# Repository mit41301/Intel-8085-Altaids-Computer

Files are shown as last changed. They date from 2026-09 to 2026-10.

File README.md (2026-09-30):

# Intel 80C85 Altaids Computer

[Build a Pocket-Sized Altair Computer](https://www.nutsvolts.com/magazine/article/build-a-pocket-sized-altair-computer) By David Hunter



Altaids_20260930T

https://www.tindie.com/products/retrocomputer/8085-chip-computer-pocket-sized-z80-altoids/

https://www.tindie.com/products/nkk_electronic/8085-sbc-altair-style-mini-board-altoids/

# Mint tin dimensions:
Top lid outer (not lip): 2.36" (59.9mm) x 3.75"(95mm)  
Tin bottom: 2.3" (58.75mm) x 3.7"(93.9mm)  
Inner: 2.24" (56.9mm) x 3.6"(91.5mm)  
Height bottom section: 0.83" (21.28mm)  
Height top section: "0.36 (9.26mm)  
Corner radius .55" (14mm)  

    "X": 91.44 mm  
    "Y": 56.896 mm  



# A85 8085 cross-assembler

A85 8085 cross-assembler can be found from Herb Johnson's [SITE](https://www.retrotechnology.com/restore/a85.html) and it works on Windows 11!

command line: A85 altaidsRom.asm -l altaids.lst -o altaids.hex

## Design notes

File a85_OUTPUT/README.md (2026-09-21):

C:\DOS\a85>a85 AltaidsROM.asm -o AltaidsROM.hex -l AltaidsROM.prn -s AltaidsROM.sym  
8085 Cross-Assembler (Portable) Ver 0.1+4  
Copyright (c) 1985,1987 William C. Colley, III  
fixes Copyright (c) 2026 Herbert R. Johnson HRJ Aug 2026  

No Errors  

[8085 Cross-Assembler](https://www.retrotechnology.com/restore/a85.html)

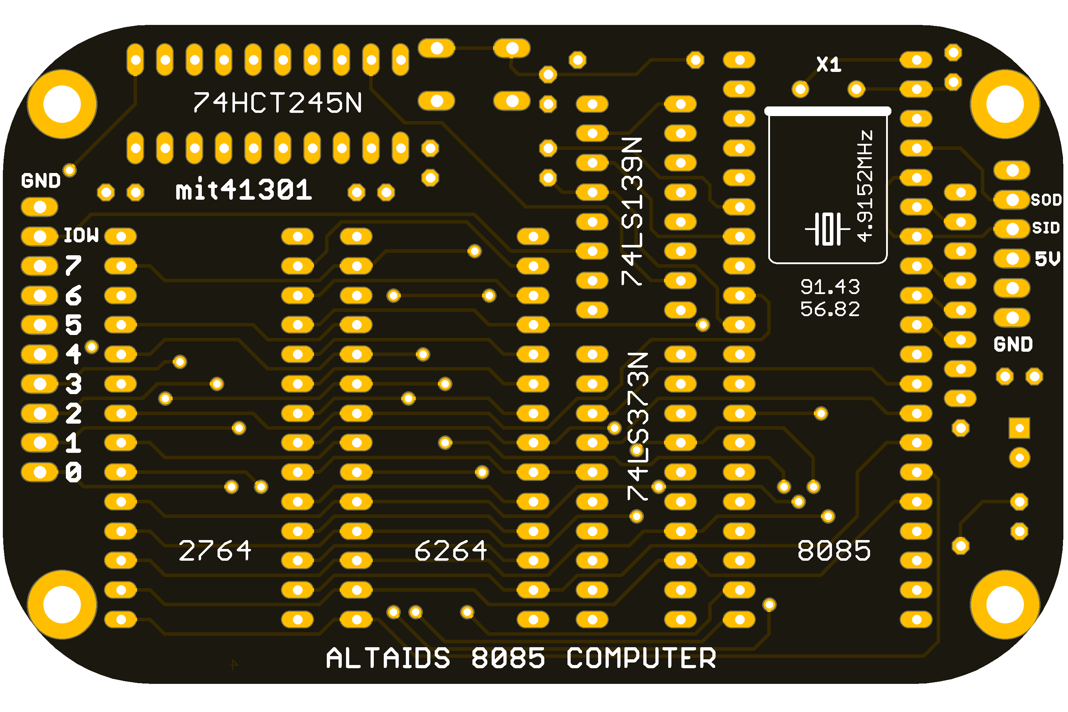
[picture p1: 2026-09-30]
Altoids_Eagle/Altaids_20260930B.png

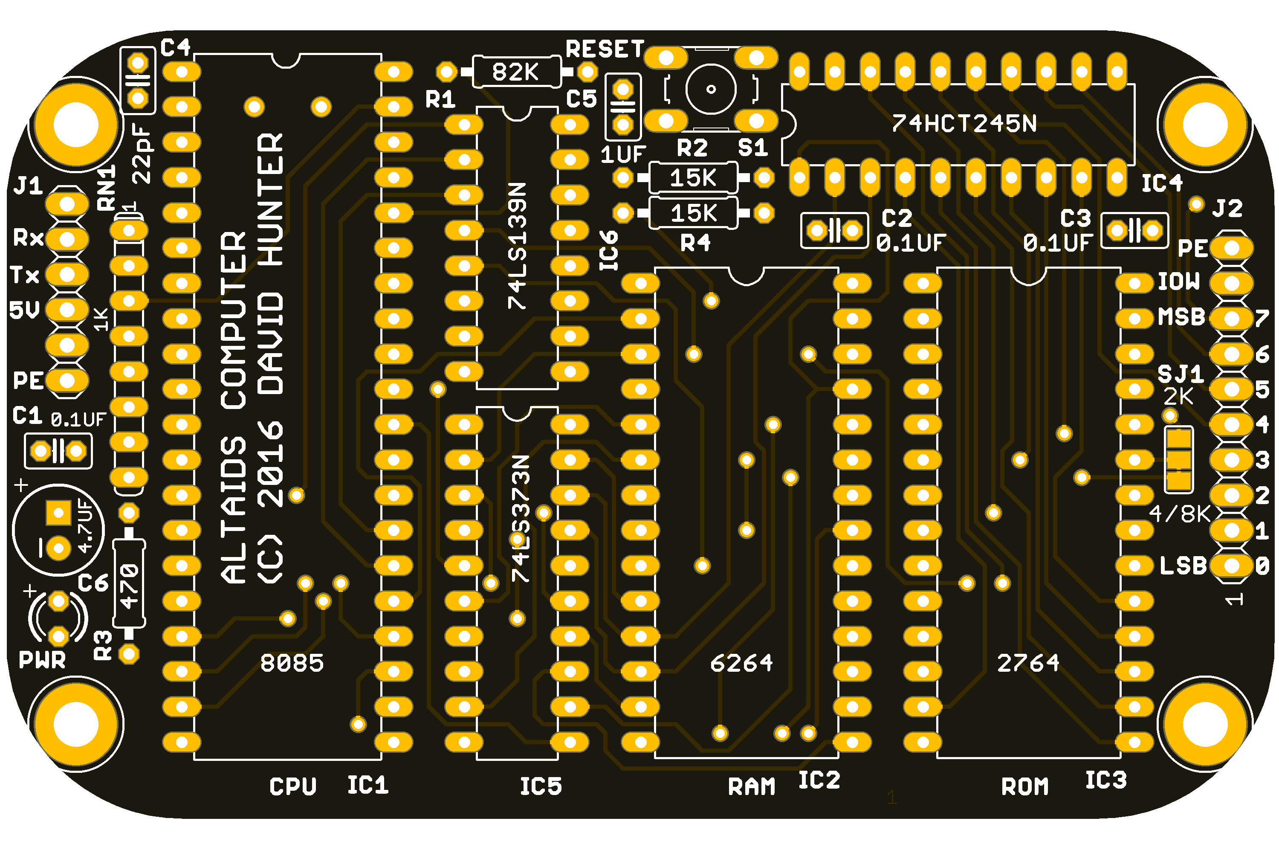
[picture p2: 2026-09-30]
Altoids_Eagle/Altaids_20260930T.png

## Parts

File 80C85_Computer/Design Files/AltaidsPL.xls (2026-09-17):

Altaids Computer
Parts List
Qty. | REF DES | Distributor P/N | Distributor | Description | Notes
3 | C1,C2,C3 | 75-1C10Z5U104M050B | Mouser | CAPACITOR, CER, 0.1UF
 |  | 332672 | Jameco | CAPACITOR, CER, 0.1UF
1 | C4 | 75-1C10C0G220J050B | Mouser | CAPACITOR, CER, 22PF
 |  | 332541 | Jameco | CAPACITOR, CER, 22PF
1 | C5 | 810-FK18X5R1E105K | Mouser | CAPACITOR, CER, 1UF
 |  | 544956 | Jameco | CAPACITOR, CER, 1UF | Re-bend leads to 0.1”
 |  | 545588 | Jameco | CAPACITOR, TANT, 1UF | Alternate
1 | C6 | 647-UVR2C4R7MED1TD | Mouser | CAPACITOR, ELECT, 4.7uF, 160V
 |  | 667-ECA-2CM4R7 | Mouser | CAPACITOR, ELECT, 4.7uF, 160V
 |  | 546071 | Jameco | CAPACITOR, TANT, 4.7uF, 25V | Alternate
1 | IC1 | 52062 | Jameco | MICROPROCESSOR, 8085
1 | IC2 | 42892 | Jameco | SRAM, 8K x 8
 |  | 913-AS6C6264A-70PCN | Mouser | SRAM, 8K x 8
1 | IC3 | 74827 | Jameco | EEPROM, 8K x 8
1 | IC4 | 45031 | Jameco | 74HCT245N
1 | IC5 | 47600 | Jameco | 74LS373N
 |  | 595-SN74LS373N | Mouser | 74LS373N
1 | IC6 | 46623 | Jameco | 74LS139N
 |  | 595-SN74LS139AN | Mouser | 74LS139N
1 | J1 | 153700 | Jameco | MALE HEADER, 1X6
 |  | 538-22-28-4063 | Mouser | MALE HEADER, 1X6
1 | J2 | 2172560 | Jameco | FEMALE HEADER, 1X10
 |  | 649-75915-310LF | Mouser | FEMALE HEADER, 1X10
1 | LED1 | 2155241 | Jameco | LED3MM
 |  | 755-SLI-343Y8C3F | Mouser | LED3MM
1 | R1 | 660-MF1/4LCT52R823G | Mouser | RESISTOR, 82K, 1/4W
 |  | 691323 | Jameco | RESISTOR, 82K, 1/4W
2 | R2,R4 | 603-MFR-25FRF5215K | Mouser | RESISTOR, 15K, 1/4W
 |  | 691147 | Jameco | RESISTOR, 15K, 1/4W
1 | R3 | 660-MF1/4LCT52R331J | Mouser | RESISTOR, 330, 1/4W
 |  | 690742 | Jameco | RESISTOR, 330, 1/4W
1 | RN1 | 652-4608X-1LF-1K | Mouser | RESISTOR NETWORK, SIP, 7POS, 1K
 |  | 97826 | Jameco | RESISTOR NETWORK, SIP, 7POS, 10K | Alternate
1 | SW1 | 162886 | Jameco | PUSHBUTTON, SPST, 4P
1 | X1 | 774-MP042 | Mouser | CRYSTAL, 4.9152MHz, HC49U
1 | IC1-S | 41136 | Jameco | Socket, 40P 0.6” DIP
 |  | 571-5-1571552-2 | Mouser | Socket, 40P 0.6” DIP
2 | IC2-S,IC3-S | 40328 | Jameco | Socket, 28P 0.6” DIP
 |  | 571-2-1571552-9 | Mouser | Socket, 28P 0.6” DIP
2 | IC4-S,IC5-S | 38623 | Jameco | Socket, 20P 0.3” DIP
 |  | 575-913204 | Mouser | Socket, 20P 0.3” DIP
1 | IC6-S | 37402 | Jameco | Socket, 16P 0.3” DIP
 |  | 571-2-1571552-4 | Mouser | Socket, 16P 0.3” DIP
4 | H1,H2,H3,H4 | 761-2100-440-AL-7 | Mouser | Hex Female Standoff, 0.25”, 4-40
 |  | 133613 | Jameco | Hex Female Standoff, 0.25”, 4-40
4 | H1,H2,H3,H4 | 2094389 | Jameco | Screw, Pan Head, Phillips, 0.25”, 4-40
 |  | 534-9900 | Mouser | Screw, Pan Head, Phillips, 0.25”, 4-40

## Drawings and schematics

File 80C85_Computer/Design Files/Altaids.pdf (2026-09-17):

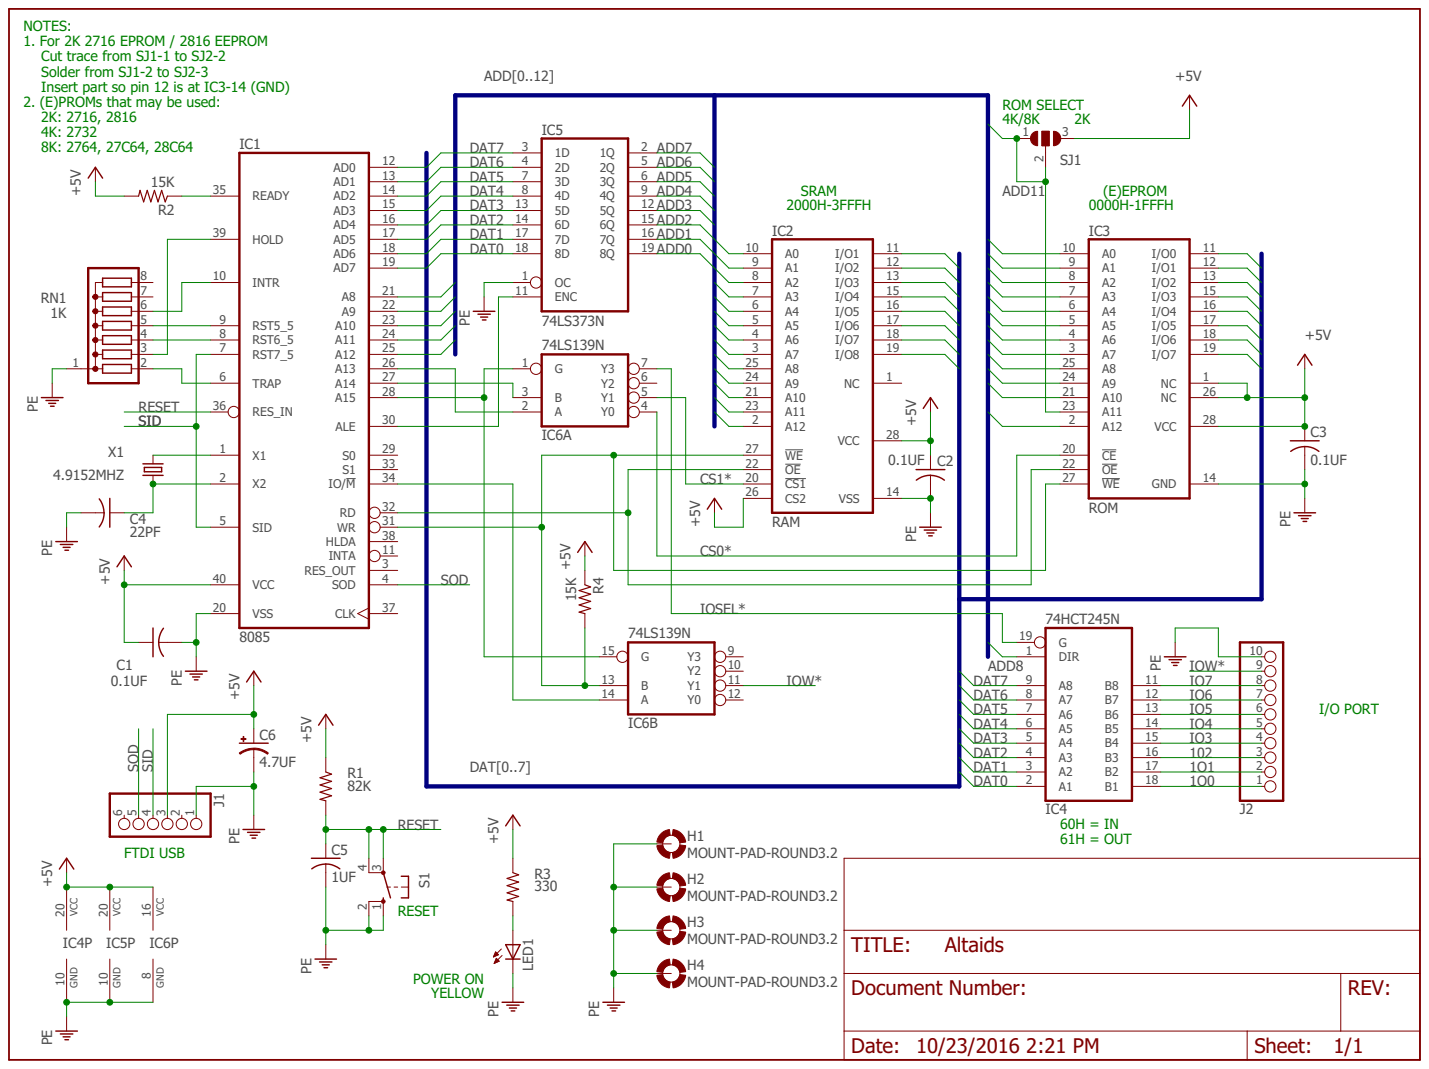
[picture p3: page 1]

NOTES: 1. For 2K 2716 EPROM / 2816 EEPROM

Cut trace from SJ1-1 to SJ2-2
Solder from SJ1-2 to SJ2-3
Insert part so pin 12 is at IC3-14 (GND)
2. (E)PROMs that may be used: 2K: 2716, 2816

Document Number: | REV:

Date: 10/23/2016 2:21 PM | Sheet: 1/1

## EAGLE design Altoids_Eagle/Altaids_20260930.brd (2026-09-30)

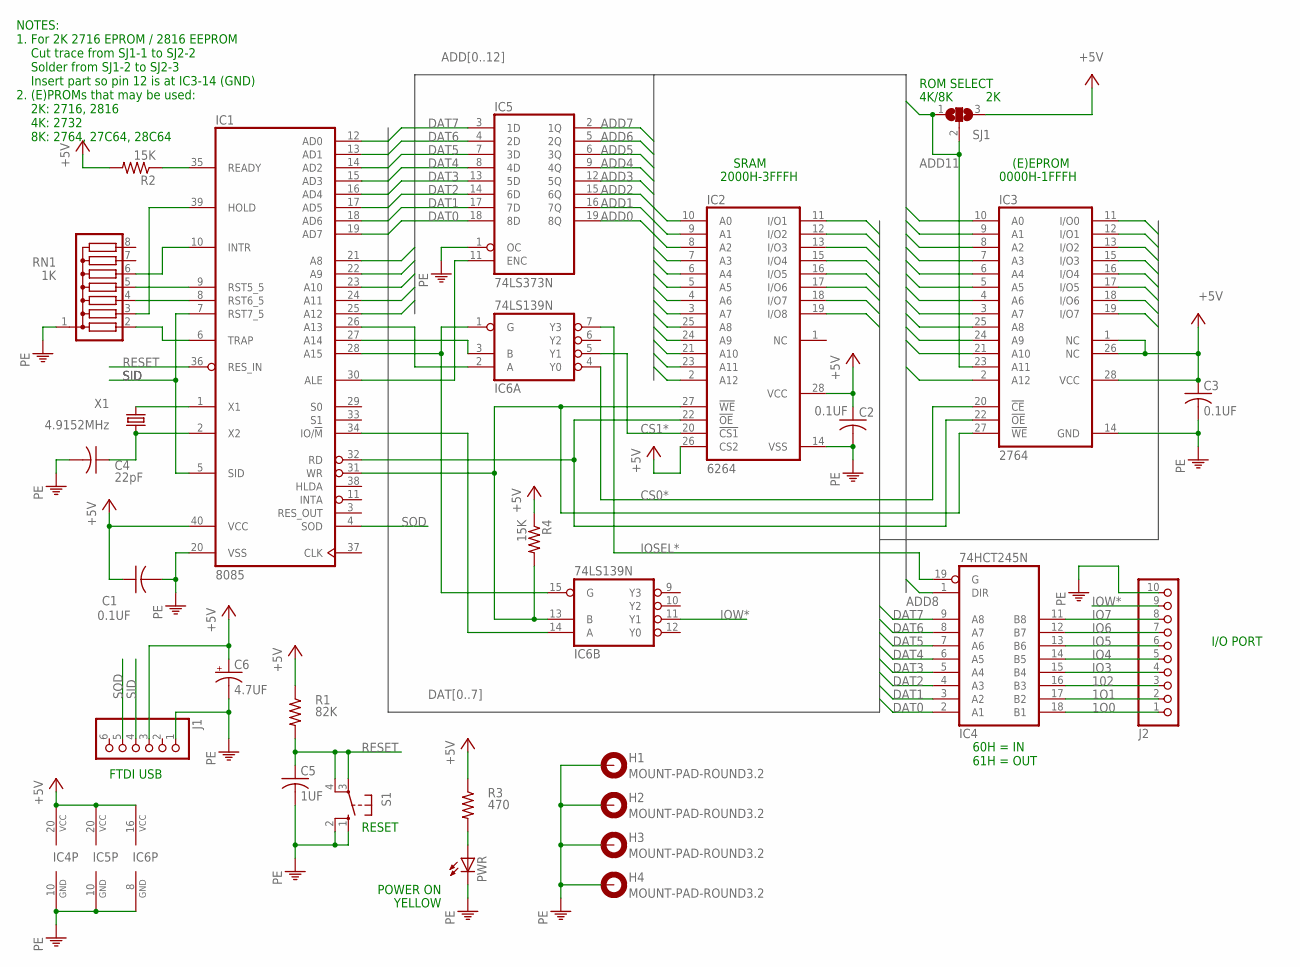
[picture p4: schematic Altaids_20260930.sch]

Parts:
C1, C2, C3: 0.1UF; C025-025X050
C4: 22pF; C025-025X050
C5: 1UF; C025-025X050
C6: 4.7UF; CPOL-RADIAL-100UF-25V
H1, H2, H3, H4: MOUNT-PAD-ROUND3.2; 3,2-PAD
IC1: 8085; DIL40
IC2: 6264; DIL28-6
IC3: 2764; DIL28-6
IC4: 74HCT245N; DIL20
IC5: 74LS373N; DIL20
IC6: 74LS139N; DIL16
J1: PINHD-1X6; 1X06
J2: PINHD-1X10; 1X10
PWR: LED3MM
R1: 82K; 0207/10
R2, R4: 15K; 0207/10
R3: 470; 0207/10
RN1: 1K; SIL8
S1: 10-XX; B3F-10XX
SJ1: SJ2W; SJ_2
X1: 4.9152MHz; HC49U-H

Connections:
1O0: IC4.18 (B1), J2.1
1O1: IC4.17 (B2), J2.2
102: IC4.16 (B3), J2.3
+5V: C1.1, C2.1, C3.1, C6.1 (+), IC1.40 (VCC), IC2.26 (CS2), IC2.28 (VCC), IC3.1 (NC), IC3.26 (NC), IC3.28 (VCC), IC4.20 (VCC), IC5.20 (VCC), IC6.16 (VCC), J1.3, R1.1, R2.2, R3.1, R4.1, SJ1.3
ADD0: IC2.10 (A0), IC3.10 (A0), IC5.19 (8Q)
ADD1: IC2.9 (A1), IC3.9 (A1), IC5.16 (7Q)
ADD2: IC2.8 (A2), IC3.8 (A2), IC5.15 (6Q)
ADD3: IC2.7 (A3), IC3.7 (A3), IC5.12 (5Q)
ADD4: IC2.6 (A4), IC3.6 (A4), IC5.9 (4Q)
ADD5: IC2.5 (A5), IC3.5 (A5), IC5.6 (3Q)
ADD6: IC2.4 (A6), IC3.4 (A6), IC5.5 (2Q)
ADD7: IC2.3 (A7), IC3.3 (A7), IC5.2 (1Q)
ADD8: IC1.21 (A8), IC2.25 (A8), IC3.25 (A8), IC4.1 (DIR)
ADD9: IC1.22 (A9), IC2.24 (A9), IC3.24 (A9)
ADD10: IC1.23 (A10), IC2.21 (A10), IC3.21 (A10)
ADD11: IC1.24 (A11), IC2.23 (A11), IC3.23 (A11), SJ1.1, SJ1.2
ADD12: IC1.25 (A12), IC2.2 (A12), IC3.2 (A12)
CS0*: IC3.20 (!CE), IC6.4 (Y0)
CS1*: IC2.20 (!CS1), IC6.5 (Y1)
DAT0: IC1.12 (AD0), IC2.11 (I/O1), IC3.11 (I/O0), IC4.2 (A1), IC5.18 (8D)
DAT1: IC1.13 (AD1), IC2.12 (I/O2), IC3.12 (I/O1), IC4.3 (A2), IC5.17 (7D)
DAT2: IC1.14 (AD2), IC2.13 (I/O3), IC3.13 (I/O2), IC4.4 (A3), IC5.14 (6D)
DAT3: IC1.15 (AD3), IC2.15 (I/O4), IC3.15 (I/O3), IC4.5 (A4), IC5.13 (5D)
DAT4: IC1.16 (AD4), IC2.16 (I/O5), IC3.16 (I/O4), IC4.6 (A5), IC5.8 (4D)
DAT5: IC1.17 (AD5), IC2.17 (I/O6), IC3.17 (I/O5), IC4.7 (A6), IC5.7 (3D)
DAT6: IC1.18 (AD6), IC2.18 (I/O7), IC3.18 (I/O6), IC4.8 (A7), IC5.4 (2D)
DAT7: IC1.19 (AD7), IC2.19 (I/O8), IC3.19 (I/O7), IC4.9 (A8), IC5.3 (1D)
IO3: IC4.15 (B4), J2.4
IO4: IC4.14 (B5), J2.5
IO5: IC4.13 (B6), J2.6
IO6: IC4.12 (B7), J2.7
IO7: IC4.11 (B8), J2.8
IOSEL*: IC4.19 (G), IC6.7 (Y3)
IOW*: IC6.11 (Y1), J2.9
unnamed: IC1.35 (READY), R2.1
unnamed: IC1.39 (HOLD), RN1.3
unnamed: IC1.10 (INTR), RN1.6
unnamed: IC1.9 (RST5_5), RN1.5
unnamed: IC1.8 (RST6_5), RN1.4
unnamed: IC1.6 (TRAP), RN1.2
unnamed: IC1.28 (A15), IC6.1 (G), IC6.15 (G)
unnamed: IC1.31 (WR), IC2.27 (!WE), IC3.27 (!WE), IC6.13 (B), R4.2
unnamed: PWR.A, R3.2
unnamed: C4.1, IC1.2 (X2), X1.1
unnamed: IC1.1 (X1), X1.2
unnamed: IC1.34 (IO/!M), IC6.14 (A)
unnamed: IC1.30 (ALE), IC5.11 (ENC)
unnamed: IC1.27 (A14), IC6.3 (B)
unnamed: IC1.26 (A13), IC6.2 (A)
unnamed: IC1.32 (RD), IC2.22 (!OE), IC3.22 (!OE)
PE: C1.2, C2.2, C3.2, C4.2, C5.2, C6.2 (-), H1.B3,2, H2.B3,2, H3.B3,2, H4.B3,2, IC1.20 (VSS), IC2.14 (VSS), IC3.14 (GND), IC4.10 (GND), IC5.1 (OC), IC5.10 (GND), IC6.8 (GND), J1.1, J2.10, PWR.K (C), RN1.1, S1.1 (S), S1.2 (S1)
RESET: C5.1, IC1.36 (RES_IN), R1.2, S1.3, S1.4 (P1)
SID: IC1.5 (SID), IC1.7 (RST7_5), J1.4
SOD: IC1.4 (SOD), J1.5

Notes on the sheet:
4K/8K
(E)EPROM
SRAM
FTDI USB
I/O PORT
ROM SELECT
POWER ON
YELLOW
RESET
60H = IN 61H = OUT
2000H-3FFFH
0000H-1FFFH
NOTES: 1. For 2K 2716 EPROM / 2816 EEPROM Cut trace from SJ1-1 to SJ2-2 Solder from SJ1-2 to SJ2-3 Insert part so pin 12 is at IC3-14 (GND) 2. (E)PROMs that may be used: 2K: 2716, 2816 4K: 2732 8K: 2764, 27C64, 28C64

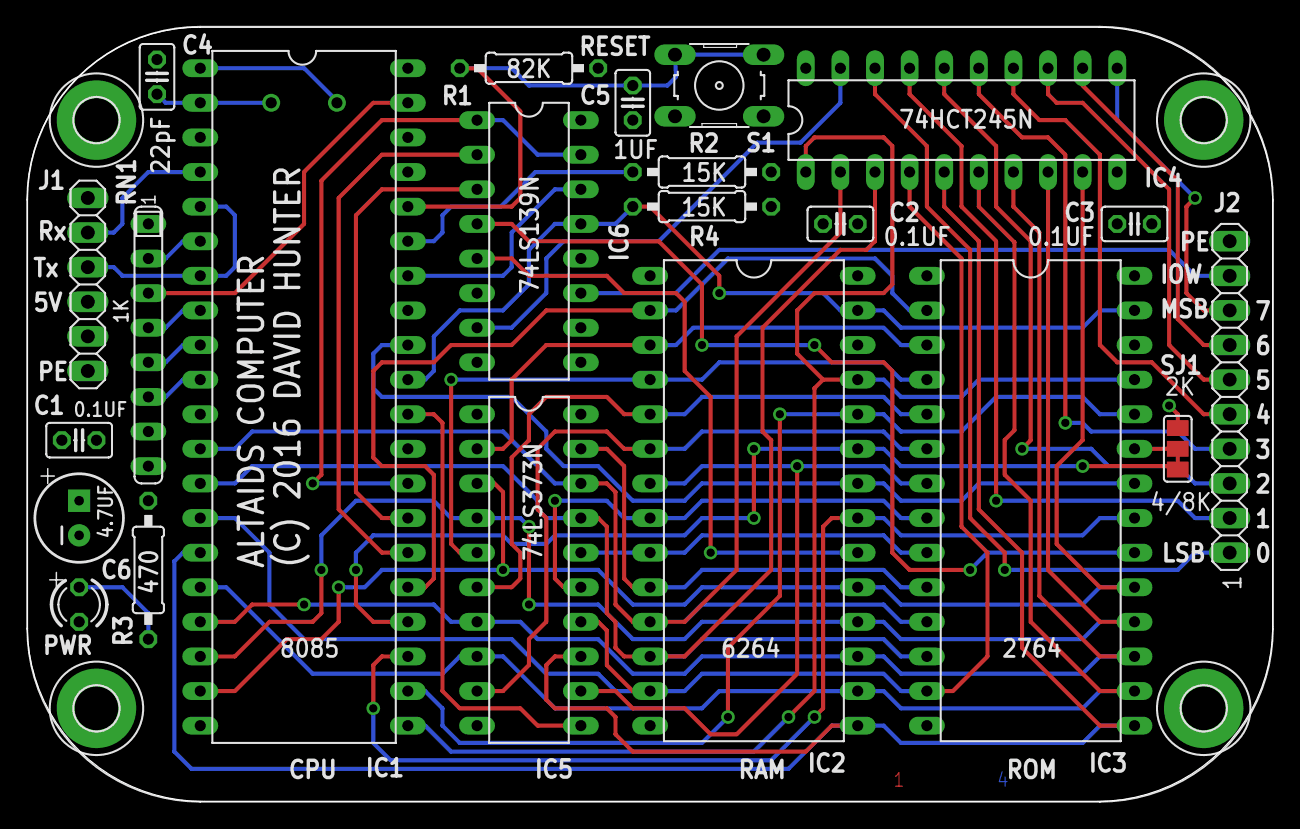
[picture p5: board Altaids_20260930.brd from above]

Board: 4 copper layers, 91.4 x 56.8 mm, 28 parts (1 on the bottom side), 54 nets.

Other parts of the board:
U$1: ALTOIDSTIN

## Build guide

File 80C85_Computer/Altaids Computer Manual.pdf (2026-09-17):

Altaids computer
Software Manual | 09/10/18

MONITOR
The operating system of the Altaids computer is a program known as a “monitor program.” This program allows for interacting with the computer over a serial port and debugging the programs. Commands consist of simple one or two letter command followed by hexadecimal values. Monitor programs were very popular with early computers. These programs allowed values to be written directly to memory, displaying memory, reading and writing Intel Hex files, etc. The monitor prompt is an asterisk '*'.

Monitor Start Up and Prompt
Altaids Monitor Ver 05
Copyright (C) 2018 David R. Hunter
This program comes with ABSOLUTELY NO WARRANTY
This is free software, and you are welcome to redistribute it under certain conditions; see the GNU GPL Version 3 for details Type "B" for BASIC, “H” for help
Type ^X to return to the Monitor
*

MONITOR COMMANDS

CMD: A
Enter Altair Turnkey Monitor (see below)

CMD: B
Start Tiny BASIC

CMD: Dssss eeee
Dump memory from address ssss to eeee. After ssss is entered, a space will automatically be generated.

CMD: Eaaaa
Write to memory starting at address aaaa. The address will be printed with the current byte. Type a new byte (in hexadecimal) to change. Press <SPACE> to skip the address leaving it unchanged. Type any other character to exit.

CMD: Gaaaa
Go (execute) a program from address aaaa

CMD: H
Help / Display monitor commands

CMD: I
Input a byte from port 60H and display

CMD: L
Load an Intel Hex file. Send the text file from the terminal emulator.
A '.' is printed for each record received correctly, a '?' if there is a checksum error, a '!' is printed when done

CMD: Obb
Output byte bb to port 61H

CMD: R
Display the values of the registers. Program Counter, Stack Pointer, Accumulator, Processor flags, BC,DE,HL. The flags are: Sign, Zero, Auxiliary carry, Parity, and Carry. An example is below

PC :SP :A SZ_A_P_C:B C :D E :H L
11CB 3F9E 22 00000100 01D2 1082 11C8

CMD: Taaaa
Single Step (trace) instructions starting at address aaaa. Type any key to step. Type ^C to exit. Each step shows the registers and a disassembled instruction. See the example below for details.

MONITOR ADDRESS VECTORS
The ROM subroutine addresses below may be useful for writing programs on the Altaids computer.

MONITOR JUMP ADDRESSES
1000 COLD | Monitor cold start
1003 WARM | Tiny BASIC warm start (return to BASIC without losing program in memory with G1003)

MONITOR VECTORS TO USEFUL ROUTINES (ENTER WITH CALL OPCODE)
1006 COUT | Output char in A to serial port
1009 CIN | Input char from serial port to A
100C PRTWD | Output H,L as 4 Hex digits to serial port
100F PRTBY | Output the byte in A as 2 Hex digits to serial port
1012 GETWD | Get Hex word from serial port, return in H,L
1015 GETBY | Get Hex byte from serial port, return in A
1018 PIN | Get byte from input port, return in A
101B POUT | Send byte in A to output port
101E DSPREG | Display registers (registers are restored upon return)
1021 PUTSTR | Send null terminated string pointed to by DE to serial port

ALTAIR MONITOR
The Altair monitor was adapted from the Altair Turnkey Monitor (TURMON) for the Altaids Computer. It is more limited than the Altaids monitor and operates with Octal values only. It is provided to “relive” the experience of operating an original Altair computer.

Altair Monitor Prompt character: '.'

Commands:
Mxxxxxx - change memory location xxxxxx (octal)
- enter 3 octal digits for new data
- press <SPACE> to skip to next location
- any other character to exit

Dxxxxxx xxxxxx - dump data from start to end address
- originally in Altair 8800b binary Absolute Tape Format
- now changed to a more standard memory dump

Jxxxxxx - jump to location and begin executing

TINY BASIC

Palo Altaids Tiny BASIC is an integer only BASIC. It is a modified version of Palo Alto Tiny BASIC by LiChen Wang. This was one of the most popular Tiny BASIC implementations for the Intel 8080.

All numbers are 16 bit values between -32767 and 32767. There are 26 variables A-Z. There is a single large one dimensional array '@(n)'. The @ array uses all remaining memory, so it's size depends on the length of the program. The number of elements is from 0 to SIZE/2. Also, one dimensional array variables may be defined using the DIM statement. Defined arrays reduce the size of memory available for the @ array.

Note, all values are decimal, so address values are expressed as decimal values. (e.g. 8192 = 0x2000)

Line numbers are from 1 to 32767. To add a line, type the line number and statement(s). To delete a line, enter the line number by itself.

There is a “one line screen editor” available which requires an ANSI compatible terminal or emulator (e.g. VT100). To edit a line, type “EDIT <line num>”. The prompt will change to ']' and the line to edit will be displayed. Use the left and right arrows to move about the line. The <DEL> key will delete the character under the cursor. The <BACKSPACE> key will delete the character to the left (unless at the line number). Any characters typed will automatically be inserted. The <ENTER> key will erase to the end of the line and exit the editor saving the line. To exit the editor and save the line press <F1>. Note, the line number cannot be changed with the editor.

Tiny BASIC can use an external computer running a terminal emulator (like TeraTerm) to load and store programs. The files are transferred using the XMODEM protocol (checksum mode only). This allows another computer to provide storage for programs. Files transferred via XMODEM typically use a “.TBI” extension. The files transferred are binary files.

When Tiny BASIC is ready, the prompt is '>'. When a command is successful there terminal will show “OK” followed by a prompt. When Tiny BASIC is entered, the following is displayed.

PALO ALTAIDS TINY BASIC VER 1.0

OK
>

BASIC COMMANDS

DIRECT COMMANDS | OPERATORS | KEYWORDS | FUNCTIONS
NEW | + | REM | RND
LIST | - | LET | ABS
RUN | * | IF | PEEK
EDIT | / | GOTO | USR
XLOAD | = | GOSUB / RETURN | INP
XSAVE | <> | INPUT | SIZE
BYE | < | PRINT | FREE
| > | STOP / END | “c”
| <= | CLS
| >= | FOR / TO / STEP / NEXT
| | GET$
| | PUT$
| | POKE
| | OUT
| | DIM
| | RANDOMIZE

Direct Commands

NEW | - clear the memory for a new program
LIST | - list the program
LIST num | - list the program starting at line “num”
RUN | - start running the program
EDIT num | - edit line “num” [ANSI terminal (or emulator) required]
XLOAD | - receive a file using XMODEM protocol (in TeraTerm: use File->Transfer->XMODEM->Send...)
XSAVE | - send a file using XMODEM protocol | (in TeraTerm: use File->Transfer->XMODEM->Receive...)
BYE | - exit Tiny BASIC and return to the monitor

Operators
The four fundamental math operations are available in addition to comparison operators. The compare operators result in a 1 if TRUE and a 0 if FALSE. The compare operators results can be used for complex operations. For example:

20 IF (U=1)*(V<2)+(U>V)*(U<99)*(V>3) PRINT “YES”

The '*' operator acts as a logical AND operation and the '+' operator acts as a logical OR operation.

Keywords

Blanks can be used freely except in numbers, keywords and function names. Keywords may be abbreviated when truncated with a period. Note, the abbreviation must be unambiguous (e.g. “GOS.” vs “GOT.” for GOSUB vs GOTO) Statements on the same line are separated by a colon (':'), however “GOTO”, “STOP”, “END” and “RETURN” must be the last command in any given statement. Also, LET is optional.

Note: expr = expression or variable var = variable num = number str = string

REM | - remark statement, ignored by Tiny BASIC
LET var=expr - set the variable to the expression
LET var=“char” - set the variable to the ASCII value of the character between the double quotes
IF expr stmt - check if expression is not zero. If so, execute the statement. (note “THEN” is not used)
- if the expression is zero, the remainder of the statement is skipped
GOTO num | - jump to statement at line number “num”
GOTO expr | - jump to the line number value determined by the expression (e.g. computed GOTO)
GOSUB num - call the subroutine at the line number “num”
GOSUB expr | - similar to GOTO except it is a call rather than a jump
RETURN | - signal the end of a subroutine and return to the statement that followed the GOSUB command
INPUT var | - input a numeric value to a variable. When executed, Tiny BASIC will print the variable name followed
| by a colon as a prompt. If the input is not valid, Tiny BASIC will print “WHAT?”
INPUT “str”var - use the string “str” as the prompt rather than the variable name.
PRINT | - if nothing follows the PRINT statement, output a CR/LF only
PRINT expr | - print the result of an expression followed by a CR/LF on the output
PRINT expr, | - print the result of an expression without a CR/LF when a comma ',' is at the end of the line
PRINT expr_ | - an underscore in the line (_) means generate a CR without a LF
PRINT #n,expr - print the variable with a fixed number of digits. The default is 6.
PRINT $expr - print the ASCII character whose value is determined by the expression. e.g. $42 = '*' PRINT “str”
PRINT 'str' - a string is quoted by either double or single quotes. Note, they cannot be mixed
- note, multiple values can be printed if separated by commas.
STOP | - exit the program and return to the user prompt
END | - same as STOP
CLS | - generate an ANSI clear screen command [ANSI terminal (or emulator) required]
FOR var=expr1 TO expr2 STEP expr3
- execute a loop from expr1 to expr2 updating variable var. The STEP parameter is optional.
- When STEP is not present, the STEP is 1
NEXT var | - end of the loop, check if expr2 has been reached, if not update var by adding expr3 (or 1) and loop
GET$ expr | - input a string from the keyboard to successive memory locations.
- Pressing ENTER stores a NULL after the string. The length of the string is returned in variable Z PUT$ expr - output the null terminated string starting from address expr.
POKE expr1,expr2
- put data from expr2 into the memory location expr1
OUT expr1,expr2
- output value of expr2 to microprocessor output port expr1 (note: Altaids output port = 97)

DIM var(num) - define a one dimensional array variable of length num. A DIM command is required for each variable e.g. DIM J(4): DIM K(5): DIM L(6)
RANDOMIZE - seed the random number generator with a hardware generated value
Tiny BASIC initializes with the same seed value after a reset. Each call to RND() will generate the same sequence. This is handy for games that generate the same sequence each time (e.g. mazes). The RANDOMIZE function will generate a random seed value (based on keypress intervals). This is useful for games in which a new random sequence is desired (e.g. card games).

Functions

RND(expr) | - return a random number between 1 and expr (inclusive)
ABS(expr) | - return the absolute value of expr
PEEK(expr) | - return the value of the byte at address expr
USR(expr) | - call the machine language subroutine at expr
USR(expr1,expr2)
- call the machine language subroutine at expr with value expr2 passed in H,L registers
- the value of the function from the machine language subroutine is returned in H,L
INP(expr) | - return value read from microprocessor input port expr (note: Altaids input port = 96)
SIZE | - return the number of bytes of memory unused by the program
FREE | - return the address of the first free byte of memory (useful for string addresses)
“char” | - return the ASCII value of a character between quotes (ASCII to decimal conversion)

Error Messages
WHAT? | - indicates that Tiny BASIC does not understand
HOW? | - indicates that the statement cannot be executed (e.g. a GOTO to a line number that doesn't exist)
SORRY? | - indicates that there is not enough memory to execute the statement

Example 1 – Tiny BASIC program
5 REM SIEVE OF ERATOSTHENES
10 INPUT "ENTER NUMBER TO SEARCH TO " L 15 IF L > 3500 GOTO 140
20 FOR I=0 TO L: @(I)=0: NEXT I
25 GOSUB 165
28 PR."STARTING CALCULATION" 30 FOR N = 2 TO X
40 IF @(N) <> 0 GOTO 80
50 FOR K = N*N TO L STEP N 60 @(K) = 1
70 NEXT K
80 NEXT N
85 PR."DONE"
90 REM DISPLAY THE PRIMES
100 FOR N = 2 TO L
110 IF @(N) = 0 PR.#5,N,
120 NEXT N
130 STOP
140 PR."ERROR: MAXIMUM NUMBER IS 3500" 150 GOTO 10
160 REM SQUARE ROOT CALCULATION
165 X = L
170 Y = 1
180 IF (X-Y)<=0 RETURN
190 X = (X+Y)/2
200 Y=L/X
210 GOTO 180
220 RETURN

Example 2 – Tiny BASIC program
2000 REM ACEY-DUECEY
2100 PR.
2101 PRINT "ACEY-DUECEY IS PLAYED IN THE FOLLOWING MANNER:" 2102 PRINT "THE DEALER (COMPUTER) DEALS TWO CARDS FACE UP." 2103 PRINT "YOU THEN BET AN AMOUNT DEPENDING ON WHETHER" 2104 PRINT "OR NOT YOU FEEL THE NEXT CARD WILL HAVE"
2105 PRINT "A VALUE BETWEEN THE FIRST TWO."
2106 PRINT "THE MINIMUM BET IS 10 DOLLARS."
2110 PR.
2120 RANDOMIZE
2170 Q=100
2190 PRINT "YOU NOW HAVE ",Q," DOLLARS." 2195 PR.
2200 GOTO 2260
2210 LET Q=Q+M
2220 GOTO 2190
2240 LET Q=Q-M
2250 GOTO 2190
2260 PRINT "HERE ARE YOUR NEXT TWO CARDS..." 2270 LET A=RND(14)
2280 IF (A<2)+(A>14) GOTO 2270
2300 LET B=RND(14)
2310 IF (B<2)+(B>14) GOTO 2300 2330 IF A>=B GOTO 2270
2340 IF B=A+1 GOTO 2270
2350 LET D=A
2360 GOSUB 3100
2500 LET D=B
2510 GOSUB 3100

2560 PR.
2660 INPUT "WHAT IS YOUR BET?"M
2670 IF M>=10 GOTO 2680
2675 PRINT "SORRY MY FRIEND, THE MINIMUM BET IS 10 DOLLARS" 2676 PR.
2677 GOTO 2660
2680 IF M<=Q GOTO 2730
2690 PRINT "SORRY MY FRIEND, BUT YOU BET TOO MUCH" 2700 PRINT "YOU HAVE ONLY ",Q," DOLLARS TO BET" 2710 GOTO 2560
2730 LET C=RND(14)
2740 IF (C<2)+(C>14)+(C=A)+(C=B) GOTO 2730 2755 PRINT "THE DRAW CARD IS :",
2760 LET D=C
2770 GOSUB 3100
2910 IF C>A GOTO 2930
2920 GOTO 2970
2930 IF C>=B GOTO 2970
2950 PRINT "YOU WIN!!!"
2955 PR.
2960 GOTO 2210
2970 PRINT "SORRY, YOU LOSE."
2975 PR.
2980 IF M<Q GOTO 2240
3010 PRINT "SORRY FRIEND, BUT YOU LOST IT ALL." 3020 PRINT
3030 PRINT "DO YOU WANT TO PLAY AGAIN?"
3040 INPUT "TYPE 1 TO PLAY AGAIN AND 0 TO EXIT"I 3060 IF I=0 GOTO 3400
3070 IF I>1 GOTO 3040
3080 IF I=1 GOTO 2110
3100 REM PRINT CARD VALUE FROM D 3110 IF D<11 PRINT #2,D:GOTO 3250 3120 IF D=11 PRINT "JACK":GOTO 3250 3130 IF D=12 PRINT "QUEEN":GOTO 3250 3140 IF D=13 PRINT "KING":GOTO 3250 3150 IF D=14 PRINT "ACE":GOTO 3250 3250 RETURN
3400 END

Example 3 – assembly language program

; DEMO.ASM
;
; ALTAIDS computer demo
; based on Altair demo from Popular Electronics, Feb 1975 ;
; COMMAND TO ASSEMBLE:
; a85 demo.asm -l demo.prn -o demo.hex
;
;
2000 | | | ORG | 2000H
2000 | 3a 80 20 | DEMO: | LDA | VAR1
2003 | 47 | | MOV | B,A
2004 | 3a 81 20 | | LDA | VAR2
2007 | 80 | | ADD | B
2008 | 32 82 20 | | STA | VAR3
200b | c3 00 20 | | JMP | DEMO
| | ;
2080 | | | ORG | 2080H
2080 | 1c | VAR1: | DB | 1CH
2081 | 08 | VAR2: | DB | 08H
2082 | 00 | VAR3: | DB | 0
2083 | | | END

Example 4 – using the monitor

Type ^X to return to the Monitor

*L | <= send file “demo.hex” from TeraTerm
.. | <= dots show status of loading the file (one dot per line)
2083 | <= first free address after program was loaded
*T2000 | <= single step the program from 0x2000

Press any key to step to the next instruction
Press ^C to return to the Monitor
PC :SP :A SZ_A_P_C:B C :D E :H L | <= identifies register values and flags
2000 3F02 00 01000100 0005 15B8 2000 LDA 2080 | <= shows current register values (in hex) and next instruction
<= press a key (e.g. <SPACE>) to show the next instruction PC :SP :A SZ_A_P_C:B C :D E :H L
2003 3F02 1C 01000100 0005 15B8 2000 MOV B,A

PC :SP :A SZ_A_P_C:B C :D E :H L
2004 3F02 1C 01000100 1C05 15B8 2000 LDA 2081

PC :SP :A SZ_A_P_C:B C :D E :H L
2007 3F02 08 01000100 1C05 15B8 2000 ADD B

PC :SP :A SZ_A_P_C:B C :D E :H L
2008 3F02 24 00010100 1C05 15B8 2000 STA 2082

PC :SP :A SZ_A_P_C:B C :D E :H L
200B 3F02 24 00010100 1C05 15B8 2000 JMP 2000

PC :SP :A SZ_A_P_C:B C :D E :H L
2000 3F02 24 00010100 1C05 15B8 2000 LDA 2080

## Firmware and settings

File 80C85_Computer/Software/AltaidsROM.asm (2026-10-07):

; Altaids ROM
; (c) 2016-2018	David R. Hunter
;
; This program is free software: you can redistribute it and/or modify
; it under the terms of the GNU General Public License as published by
; the Free Software Foundation, version 3 of the License.
;
; This program is distributed in the hope that it will be useful,
; but WITHOUT ANY WARRANTY; without even the implied warranty of 
; MERCHANTABILITY or FITNESS FOR A PARTICULAR PURPOSE.  See the
; GNU General Public License for more details.
;
; You should have received a copy of the GNU General Public License
; alog with this program.  If not, see <https://www.gnu.org/licenses/>.
;
;
; Included are three programs in the 8K EPROM of the Altaids Computer:
;	1. TINY BASIC with a single line editor (ANSI Terminal) and XMODEM SAVE/LOAD
;	2. Altair Turnkey Monitor (to recreate the "feel" of an Altair and terminal)
;	3. 8085 Monitor with Intel Hex file load and single step trace capability
;
; This program source has a mix of "styles" because it is a 
; combination of programs from different sources (see ACKNOWLEDGMENTS).
; To be true to the authors of those programs, I tried to keep the style 
; of the originals
;  Dave Hunter
;
;
; ACKNOWLEDGEMENTS:
;
; Developed with A85: 8085 Cross-Assembler Ver 0.1 by William C. Colley, III
;   incorporating fixes for LCC/Windows by HRJ Dec 2013
;
; command line: A85 altaidsRom.asm -l altaids.lst -o altaids.hex
;
; The BASIC is adapted Palo Alto Tiny BASIC (PATB) by LiChen Wang DDJ June 1976
; using features of the Sherry Brothers version
;
; GET$ AND PUT$ are adapted from DDJ Feb 1977, 
; EXTENSIONS TO WANG'S PALO ALTO TINY BASIC by Russ Hayden
;
; RND is the 16-bit Random Number Generator from the web site:
; www.map.grauw.nl/sources/external/z80bits.html#4.2
; by Milos "Baze" Bazelides
; and converted from Z-80 to 8080
;
; The ^C interrupt, editor, XMODEM routines and other enhancements to PATB
; are by David Hunter 2016-2018
;
; The Altair monitor is adapted from TURMON by MITS (C)1977
;
; The 8085 monitor is by David Hunter March 2018
;
; The single step was adapted and modified from:
; SINGLE STEPPING THE 8080 PROCESSOR
; By Charles Sharp BYTE Magazine January 1979
;
; The 8085 disassembler is by David Hunter 2017
;
; The serial port routines are adapted from:
; The MCS-80/85 Family User's Manual by Intel 1986 
;
;
; The Altaids computer features:
; 8K of E(E)PROM and 8K of RAM equivalent to a 16K Altair  
; The serial port uses the SID/SOD pins of the 8085 as a software UART
; There is one 8 bit I/O port which can be used for either input or output
;
; This is similar to the following configuration:
;	Altair 8800b Turnkey Model w/ CPU board	
; 	one 88-PMC8 8K ROM card
;	two 88-4MCS 4K SRAM cards
;	one 88-SIO serial I/O board
;	one 88-PIO parallel I/O board
;
; Giving you a turnkey Altair with power supply and 6 cards in a mint tin!
;
; Hardware Memory Map:
;	0000H - 0EFFH	EPROM: TINY BASIC
;	0F00H - 0FFFH	EPROM: ALTAIR TURNKEY MONITOR
;	1000H - 1BFFH	EPROM: 8085 MONITOR
;	1C00H - 1FFFH	EPROM: unused
;	2000H - 3FFFH	SRAM
;	4000H - 5FFFH	unavailable
;	6000H - 7FFFH	RESERVED (decoded with I/O)
;	8000H - FFFFH	OPEN
;
;
; I/O Map:
;	00H - 5FH	unavailable
;	60H - 7FH	external I/O port
;	80H - FFH	unavailable
;
; Input Port:	60H
; Output Port:	61H
;
; Serial interface: 2400 baud, 8N1, Flow control: None
;
; Because of processing of the serial data, sending text files from TeraTerm
; requires delays for character and lines.  I found the following settings
; very reliable:
; Transmit delay =
;	50 msec/char
;	200 msec/line
;
;
	TITLE	"Altaids ROM VER 5"
;
;	06/14/16	D. Hunter - started project
;	05/07/17	D. Hunter - editor and disassembler complete
;	07/04/17	D. Hunter - added XMODEM Load/Save to Tiny BASIC
;	03/15/18	D. Hunter - added Altair TURMON (modified)
;				  - replaced monitor with my own version
;	04/22/18	D. Hunter - added 1D arrays to Tiny BASIC
;				  - added RANDOMIZE keyword to change random seed
;
;
;
VERS	EQU	'50'	; Version number (2 bytes)
;			  BYTES REVERSED FOR DISPLAY ORDER
;			  e.g. 20 == '0',' 2'
BUFSIZ	EQU	80	; BUFFER SIZE
;
;*******************************************
; CONSTANTS
;
; CONSTANTS FOR 2400 BAUD SERIAL I/O
; USING A 4.9152MHZ CRYSTAL GIVES A 2.4576MHZ CLOCK
; SEE THE INTEL MCS-80/85 FAMILY USER'S MANUAL PG A1-28
; FOR DETAILS.  
HALFBIT	EQU	38	
FULLBIT	EQU	69	; true bit rate = 2388 bps  
; HALFBIT EQU 46  
; FULLBIT EQU 84 ; are for a 6MHz clock.  
;
; HARDWARE GPIO PORTS
GPI	EQU	60H	; INPUT PORT
GPO	EQU	61H	; OUTPUT PORT
;
; ASCII CONSTANTS
PROMPT	EQU	'*'	; MONITOR PROMPT CHARACTER
APROMPT	EQU	'.'	; ALTAIR MONITOR PROMPT
BPROMPT	EQU	'>'	; BASIC PROMPT 
EPROMPT	EQU	']'	; EDITOR PROMPT
CTRC	EQU	3	; ^C
CTRD	EQU	4	; ^D
BELL	EQU	7	; ^G BELL
CTRH	EQU	8	; ^H BACKSPACE
TAB	EQU	9	; ^I
CTRO	EQU	15	; ^O TOGGLE OUTPUT
CTRX	EQU	24	; ^X, ABORT
BACKUP	EQU	CTRH	; BACKUP CHAR
DEL	EQU	127	; RUBOUT
ESC	EQU	27	; ESCAPE
CR	EQU	13	; CARRIAGE RET
LF	EQU	10	; LINE FEED
;
RLEN	EQU	16	; RECORD LENGTH FOR HEX DUMP
;
;
; INTERRUPT ENABLE BIT FROM RIM INSTRUCTION
IEFLG	EQU	08H	; SET IF INTERRUPTS ARE ENABLED
;
; XMODEM CONSTANTS
ACK	EQU	06H		; ACKNOWLEDGE
NAK	EQU	15H		; NO ACKNOWLEDGE
SOH	EQU	01H		; START OF DATA
EOT	EQU	04H		; END OF DATA
CAN	EQU	18H		; CAN CHARACTER (^X)
BLKSIZ	EQU	128		; NUMBER OF BYTES PER BLOCK
ONESEC	EQU	24824		; ONE SECOND TIME OUT FOR 2.4576MHZ CLOCK
MAXTRY	EQU	3		; MAXIMUM RETRY COUNT
MAXTIM	EQU	10		; MAXIMUM TIMEOUT COUNT (SECONDS)
;
;*******************************************
; RESTART (RST) AREA
	ORG	0	; RST 0
ROMST:	DI		; START OF ROM, DISABLE INTERRUPTS
	JMP	START	; GO TO THE MONITOR FIRST
	DB	'WANG'
;	
	ORG	08H
	XTHL		;*** TSTC OR RST 1 *** 
	RST	5	;IGNORE BLANKS AND 
	CMP	M	;TEST CHARACTER
	JMP	TC1	;REST OF THIS IS AT TC1
;
CRLF:	MVI	A,CR 	;*** CRLF ***
;	
	ORG	10H
	PUSH	PSW	;*** OUTC OR RST 2 *** 
	LDA	OCSW	;PRINT CHARACTER ONLY
	ORA	A	;IF OCSW SWITCH IS ON
	JMP	OC2	;REST OF THIS IS AT OC2
;	
	ORG	18H
	CALL	EXPR2	;*** EXPR OR RST 3 *** 
	PUSH	H	;EVALUATE AN EXPRESION 
	JMP	EXPR1	;REST OF IT IS AT EXPR1
	DB	'E' 
;	
	ORG	20H
	MOV	A,H	;*** COMP OR RST 4 *** 
	CMP	D	;COMPARE HL WITH DE
	RNZ		;RETURN CORRECT CY AND
	MOV	A,L	;Z FLAGS 
	CMP	E	;BUT OLD A IS LOST 
	RET
	DB	'T '
;	
	ORG	28H
SS1:	LDAX	D	;*** IGNBLK/RST 5 ***
	CPI	' '	;IGNORE BLANKS 
	RNZ		;IN TEXT (WHERE DE->)
	INX	D	;AND RETURN THE FIRST
	JMP	SS1	;NON-BLANK CHAR. IN A
;	
	ORG	30H
	POP	PSW	;*** FINISH/RST 6 ***
	CALL	FIN	;CHECK END OF COMMAND
	JMP	QWHAT	;PRINT "WHAT?" IF WRONG
	DB	'A' 
;	
	ORG	38H	;*** TSTV OR RST 7 *** 
	JMP	TSTV0	;JUMP AROUND INTERRUPT
	DB	'L'
;	
;*******************************************
; SERIAL INTERRUPT
; THIS ROUTINE LOOKS FOR A ^C CHARACTER AND
; SETS THE ABORT FLAG IF ONE OCCURS
;
; ^C = 03H	= 00000011B
; SERIAL DATA IS LSB FIRST, SO THE SEQUENCE
; OF BITS ON THE INTERRUPT PIN IS:
;  0:11000000:1
;  S          P
;  S = START, P = STOP
;  THE TRANSISTION FROM START BIT TO BIT 0 
;  CAUSES THE INTERRUPT.   BY LOOKING FOR THE
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

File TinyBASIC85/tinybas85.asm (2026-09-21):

        PAGE 0                ;SUPPRESS FF ADDED IN LIST FILE
;*************************************************************
;
;                 TINY BASIC FOR INTEL 8085
;                       VERSION 2.X
;                     BY LI-CHEN WANG
;                  MODIFIED AND TRANSLATED
;                    TO INTEL MNEMONICS
;                     BY ROGER RAUSKOLB
;                      10 OCTOBER,1976
;                        @COPYLEFT
;                   ALL WRONGS RESERVED
;              ADDITIONS BY ANDERS HJELM 2020
;
;*************************************************************
;
; *** 8085 ADDITIONAL INSTRUCTIONS ***
;
; UNDOCUMENTED INSTRUCTIONS FOR THE 8085 CPU SUPPLIED AS MACROS
;
DSUB    MACRO                 ;16-BIT SUBTRACT: HL = HL - BC
        DB    08H
        ENDM
;
ARHL    MACRO                 ;ARITHMETIC SHIFT RIGHT OF HL
        DB    10H
        ENDM
;
RDEL    MACRO                 ;ROTATE LEFT THROUGH CARRY OF DE
        DB    18H
        ENDM
;
LDHI    MACRO BARG1           ;LOAD DE WITH HL + IMMEDIATE BYTE
        DB    28H
        DB    BARG1
        ENDM
;
LDSI    MACRO BARG2           ;LOAD DE WITH SP + IMMEDIATE BYTE
        DB    38H
        DB    BARG2
        ENDM
;
RSTV    MACRO                 ;RESTART ON OVERFLOW ("CV 0040H")
        DB    0CBH
        ENDM
;
SHLX    MACRO                 ;STORE HL INDIRECT THROUGH (DE)
        DB    0D9H
        ENDM
;
LHLX    MACRO                 ;LOAD HL INDIRECT THROUGH (DE)
        DB    0EDH
        ENDM
;
JNK     MACRO WARG1           ;JUMP ON NOT K-FLAG
        DB    0DDH
        DB    (WARG1 & 0FFH)
        DB    (WARG1 >> 8)
        ENDM
;
JK      MACRO WARG2           ;JUMP ON K-FLAG
        DB    0FDH
        DB    (WARG2 & 0FFH)
        DB    (WARG2 >> 8)
        ENDM
;
; *** TABLE/ADDRESSING MACRO ***
;
; USING TWO BYTE ADDRESS WITH MOST SIGNIFICANT BIT SET TO 1
;
DWA     MACRO WHERE
        DB   (WHERE >> 8) + 128
        DB   WHERE & 0FFH
        ENDM
;
;*************************************************************
;
; *** ZERO PAGE SUBROUTINES ***
;
; THE 8080 INSTRUCTION SET LETS YOU HAVE 8 ROUTINES IN LOW
; MEMORY THAT MAY BE CALLED BY RST N, N BEING 0 THROUGH 7.
; THIS IS A ONE BYTE INSTRUCTION AND HAS THE SAME POWER AS
; THE THREE BYTE INSTRUCTION CALL LLHH.  TINY BASIC WILL
; USE RST 0 AS START AND RST 1 THROUGH RST 7 FOR
; THE SEVEN MOST FREQUENTLY USED SUBROUTINES.
; TWO OTHER SUBROUTINES (CRLF AND TSTNUM) ARE ALSO IN THIS
; SECTION.  THEY CAN BE REACHED ONLY BY 3-BYTE CALLS.
; BY USING RST CALLS, ROM CODE IS REDUCED BY ABOUT 200 BYTES.
;
        ORG  0H
START:  LXI  SP,STACK           ;*** COLD START ***
        MVI  A,80H
        JMP  INIT
;
TSTC:   XTHL                    ;*** TSTC OR RST 1 *** (24x)
        RST  5                  ;IGNORE BLANKS AND
        CMP  M                  ;TEST CHARACTER
        JMP  TC1                ;REST OF THIS IS AT TC1
;
CRLF:   MVI  A,CR               ;*** CRLF ***
;
OUTC:   PUSH PSW                ;*** OUTC OR RST 2 *** (22x)
        JMP  OC3                ;REST OF THIS IS AT OC3
;
RIMSK:  RIM                     ;*** READ INTERRUPT MASK ***
        MOV  L,A                ;PLACE RESULT IN L
        RET                     ;THAT'S ALL
        NOP                     ;DUMMY FILL BYTE
;
EXPR:   CALL EXPR0              ;*** EXPR OR RST 3 *** (11x)
        PUSH H                  ;EVALUATE AN EXPRESSION
        JMP  RELOP              ;REST OF IT AT RELOP
        DB   'W'
;
COMP:   MOV  A,H                ;*** COMP OR RST 4 *** (16x)
        CMP  D                  ;COMPARE HL WITH DE
        RNZ                     ;RETURN CORRECT C AND
        MOV  A,L                ;Z FLAGS
        CMP  E                  ;BUT OLD A IS LOST
        RET
        DB   "AN"
;
IGNBLK: LDAX D                  ;*** IGNBLK/RST 5 *** (7x)
        CPI  ' '                ;IGNORE BLANKS
        RNZ                     ;IN TEXT (WHERE DE->)
        INX  D                  ;AND RETURN THE FIRST
        JMP  IGNBLK             ;NON-BLANK CHAR. IN A
;
FINISH: POP  PSW                ;*** FINISH/RST 6 *** (16x)
        CALL FIN                ;CHECK END OF COMMAND
        CALL QWHAT              ;PRINT "WHAT?" IF WRONG
        DB   'G'
;
XPR40:  JMP  XP40               ;*** XP40 OR RST 7 *** (24x)
        NOP                     ;DUMMY FILL BYTE
;
TIMINT: DI                      ;*** TIMER/RST 7.5 ***
        PUSH H                  ;DURATION 40us EVERY 1ms
        PUSH PSW                ;ONLY ABOUT 2.5% OVERHEAD
        LHLD TIMCNT             ;GET TIMER COUNT
        INX  H                  ;AND INCREMENT IT
        SHLD TIMCNT
        MVI  A,10H              ;RESET THE RST 7.5 F/F
        SIM
        POP  PSW
        POP  H
        EI
        RET
;
TSTV:   RST  5                  ;*** TSTV ***
        SUI  '@'                ;TEST VARIABLES
        RC                      ;C:NOT A VARIABLE
        JNZ  TV1                ;NOT "@" ARRAY
        INX  D                  ;IT IS THE "@" ARRAY
        CALL PARN               ;@ SHOULD BE FOLLOWED
        DAD  H                  ;BY (EXPR) AS ITS INDEX
        CC   QHOW               ;IS INDEX TOO BIG?
        PUSH D                  ;WILL IT OVERWRITE
        XCHG                    ;TEXT?
        CALL FREE               ;FIND SIZE OF FREE MEM
        RST  4                  ;AND CHECK THAT
        CC   ASORRY             ;IF SO, SAY "SORRY"
        LXI  H,VARBGN           ;IF NOT GET ADDRESS
        CALL SUBDE              ;OF @(EXPR) AND PUT IT
        POP  D                  ;IN HL
        RET                     ;C FLAG IS CLEARED
TV1:    CPI  1BH                ;NOT @, IS IT A TO Z?
        CMC                     ;IF NOT RETURN C FLAG
        RC
        INX  D                  ;IF A THROUGH Z
        LXI  H,VARBGN           ;COMPUTE ADDRESS OF
        RLC                     ;THAT VARIABLE
        ADD  L                  ;AND RETURN IT IN HL
        MOV  L,A                ;WITH C FLAG CLEARED
        MVI  A,0
        ADC  H
        MOV  H,A
        RET
;
;TSTC:  XTHL                    ;*** TSTC OR RST 1 ***
;       RST  5                  ;THIS IS AT LOC. 8
;       CMP  M                  ;AND THEN JUMP HERE
TC1:    INX  H                  ;COMPARE THE BYTE THAT
        JZ   TC2                ;FOLLOWS THE RST INST.
        PUSH B                  ;WITH THE TEXT (DE->)
        MOV  C,M                ;IF NOT =, ADD THE 2ND
        MVI  B,0                ;BYTE THAT FOLLOWS THE
        DAD  B                  ;RST TO THE OLD PC
        POP  B                  ;I.E., DO A RELATIVE
        DCX  D                  ;JUMP IF NOT =
TC2:    INX  D                  ;IF =, SKIP THOSE BYTES
        INX  H                  ;AND CONTINUE
        XTHL
        RET
;
TSTNUM: LXI  H,0                ;*** TSTNUM ***
        MOV  B,H                ;TEST IF THE TEXT IS
        RST  5                  ;A NUMBER
        CPI  27H                ;TEST FOR SINGLE QUOTE
        JNZ  TN0                ;NO, TRY HEXADECIMAL
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

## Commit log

2026-09-19 X = 91.44 mm and Y = 56.896 mm
    [adafruit minty permaproto.brd, adafruit minty permaproto.sch]
2026-09-30 New Silkscreen - Edited
    [Altaids_20260930.brd, Altaids_20260930.sch]
2026-09-30 Assembler for 8085

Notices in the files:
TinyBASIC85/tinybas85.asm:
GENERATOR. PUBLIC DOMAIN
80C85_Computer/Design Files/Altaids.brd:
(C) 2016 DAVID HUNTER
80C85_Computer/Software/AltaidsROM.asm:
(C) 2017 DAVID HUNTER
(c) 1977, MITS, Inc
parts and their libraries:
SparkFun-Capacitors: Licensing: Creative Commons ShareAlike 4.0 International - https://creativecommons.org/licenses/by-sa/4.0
